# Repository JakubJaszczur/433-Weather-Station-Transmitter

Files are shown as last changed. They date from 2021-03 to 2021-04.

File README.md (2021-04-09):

<p align="center">
  <a href="" rel="noopener">
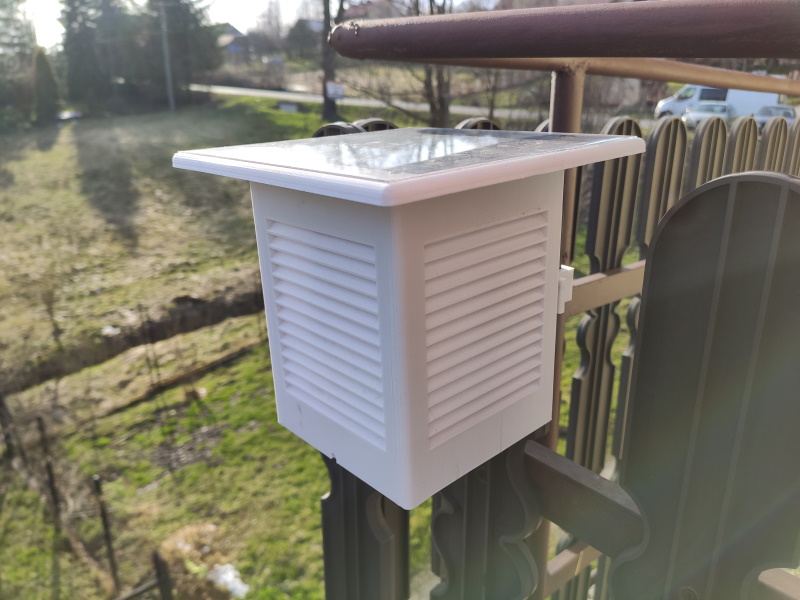
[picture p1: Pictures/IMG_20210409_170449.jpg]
Device
 </a>
</p>

<h1 align="center">Weather Station Transmitter</h1>

<div align="center">

[]()




</div>

---

<p align="center"> Weather Station based on HC12 transceiver
    <br> 
</p>

## Table of Contents

- [About](#about)
- [Features](#features)
- [Bill of Materials](#bill)
- [Libraries](#libraries)
- [Getting Started](#getting_started)
- [Description](#description)
- [Changelog](#changelog)
- [Task list](#task)
- [Pictures](#pictures)

## 1. About 

Weather Station powered by 18650 Li-ion battery, charged by solar panel. 433MHz HC-12 module is used to send data formatted in JSON. The project is a part of bigger IOT system, and is related to my other projects:

- [Epaper Weather Station Receiver](https://github.com/JakubJaszczur/Epaper-Weather-Station-Receiver "Epaper Weather Station Receiver")
- [Lora & HC12 to MQTT gateway](https://github.com/JakubJaszczur/LORA-433-Gateway "LORA 433 Gateway")

## 2. Features 

* Various sensors - temperature, humidity, pressure, light intensity, UV index, PM2.5, PM10
* Battery and solar panel voltage measurements
* Possibility to add more sensors (e.g. by I2C)
* Deep sleep to save power
* Debug mode

## 3. Bill of Materials 

Main components:

| Device  		 | Description 	 | Price		  | 
| --- | --- |---|
| Arduino Nano V3 | Main IC (clone) |	$2.50 |
| BME280 | Temperature, humidity, pressure sensor  |	$2.10 |
| MCP9808 | High accuracy temperature sensor | $0.75 |
| BH1750 | Light sensor | $1.00 |
| SI1145 | UV index sensor | $3.70 |
| PMS3003 | Dust sensor | $13.40 |
| HC12 | 433MHz transceiver | $1.95 |
| J5019 | Battery charger with DC-DC converter | $0.69 |
| 2000mAh Li-Ion  | 18650 Battery | $2.20 |
| 18650 holder | 18650 Battery holder | $0.35 |
| PC,B | Custom PCB | |
| Housing | Custom housing (3D printed) | |
<br>
## 4. Libraries 

- [ArduinoJson](https://github.com/bblanchon/ArduinoJson "ArduinoJson")
- [Adafruit MCP9808](https://github.com/adafruit/Adafruit_MCP9808_Library "Adafruit_MCP9808")
- [Adafruit BME280](https://github.com/adafruit/Adafruit_BME280_Library "Adafruit_BME280")
- [Adafruit Sensor](https://github.com/adafruit/Adafruit_Sensor "Adafruit_Sensor")
- [Adafruit SI1145](https://github.com/adafruit/Adafruit_SI1145_Library "Adafruit_SI1145")
- [BH1750 by Claws](https://github.com/claws/BH1750 "BH1750")
- [PMserial by Alvaro Valdebenito](https://github.com/avaldebe/PMserial "PMserial")

## 5. Getting Started 

To run Weather Station, user should change some settings:

Node ID - used to identify device by receiver 
```
#define NODE_ID           103   // Device ID, for internal purpose
```
Sleep time - how often device will wake up and send measurements 
```
#define SLEEP_TIME        37    // x * 8s = sleep time
```
Calibration factors - booth should be 1.0 at the beginning, later can be adjusted to fit measured voltages to real values
```
#define BAT_FACTOR        0.979981    // a = y/x, calibration factor
#define PAN_FACTOR        0.986017    // a = y/x, calibration factor
```
Altitude - set real value of your location, used for pressure readings
```
#define ALTITUDE        515.0 //define altitude of location
```

## 6. Description 

#### Measurements
- <b>Temperature:</b> measured by MCP9808 to ensure high accuracy (0,25&ordm;C)
- <b>Humidity, Pressure:</b> measured by BME280
- <b>Light:</b> measured by BH1750 (lux)
- <b>UV index:</b> measured by SI1145
- <b>PM2.5, PM10:</b> measured by PMS3003 
- <b>Voltages:</b> battery and solar panel voltages measured by analog inputs

#### Output Parameters

Measurements send by device using HC-12:

```json
{
  "id":103,
  "te":4,       // temperature
  "hu":72,      // humidity
  "pr":1024.8,  // pressure
  "p2":34,      // PM2.5
  "p1":45,      // PM10
  "ba":4.07,    // battery voltage
  "pa":4.794    // solar panel voltage
}
```

## 7. Changelog 

2021-04-09 <b>V1.0</b> Stable version  

## 8. Task list 

 Software:

- [ ] Service commands (receive data, e.g. calibration factors, sleep time and store in EEPROM)

Hardware:
- [ ] Add additional capacitor to Vcc for better stability
- [ ] Change MOSFET circuit - Q1 should be connected to GND, add gate-source resistor 
- [ ] For future - add anemometer, rainmeter, wind direction etc.

## 9. Pictures 

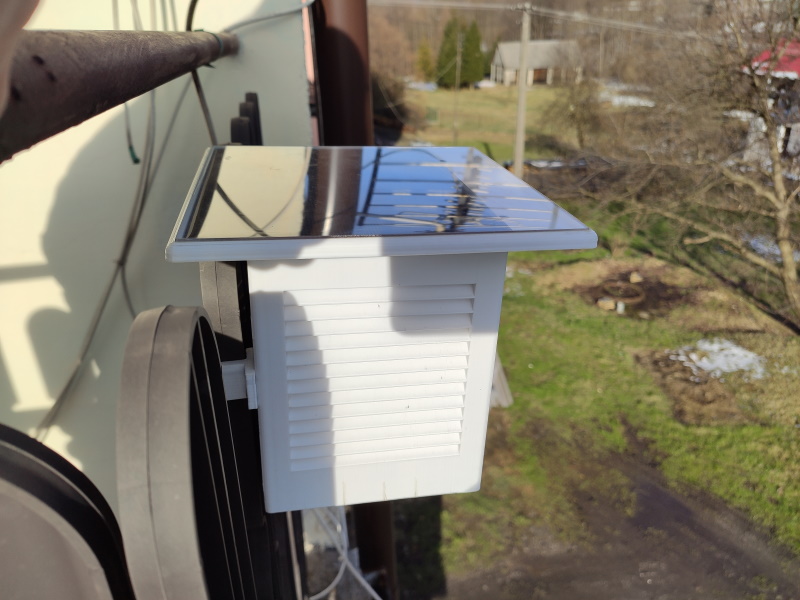
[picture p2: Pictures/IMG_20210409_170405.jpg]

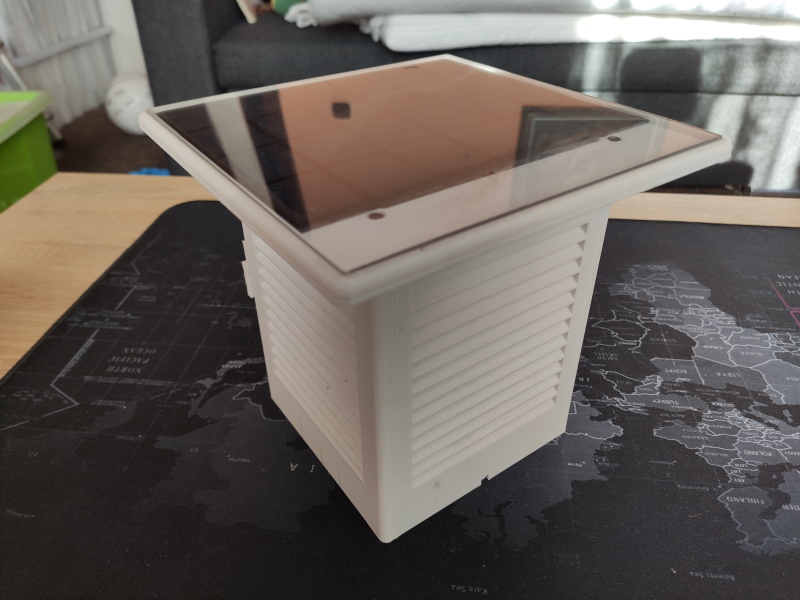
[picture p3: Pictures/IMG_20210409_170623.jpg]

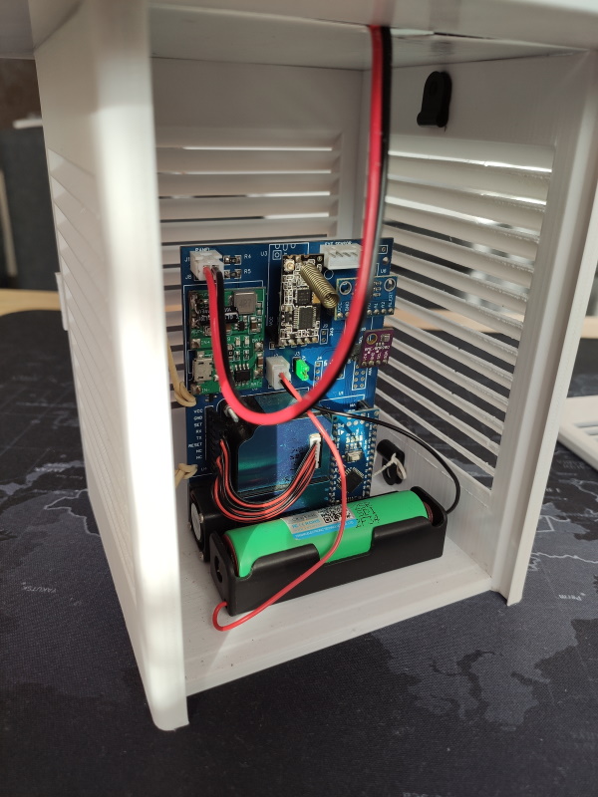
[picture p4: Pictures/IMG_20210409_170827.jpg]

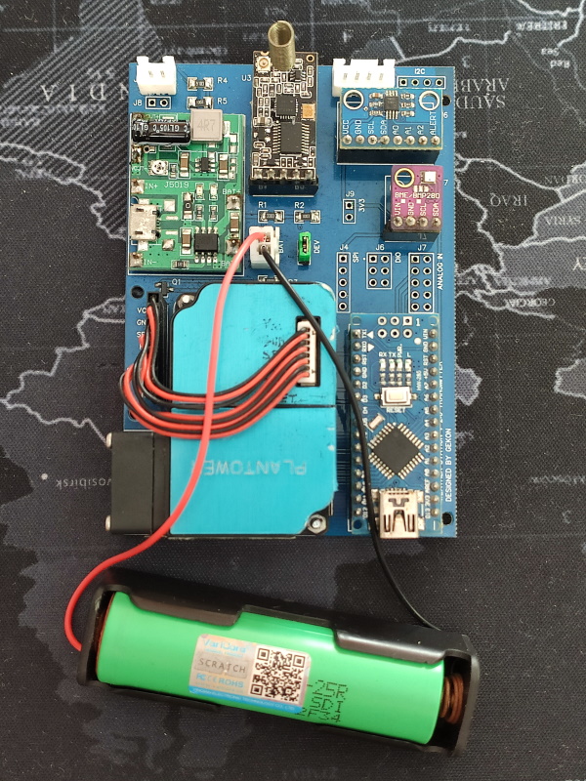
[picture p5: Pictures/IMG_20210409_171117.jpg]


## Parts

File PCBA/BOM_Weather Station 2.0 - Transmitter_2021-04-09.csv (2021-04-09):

ID | Name | Designator | Footprint | Quantity | Manufacturer Part | Manufacturer | Supplier | Supplier Part | Price | LCSC Assembly
1 | Header-Male-2.54_1x2 | J1,J2,J3,J8,J9 | HDR-2X1/2.54 | 5 | 826629-2 | TE Connectivity | LCSC | C86471 | 0.2091
2 | Header-Male-2.54_1x5 | J4 | HDR1X5 | 1 | 210S-1*5P L=11.6MMGold-plated black | Ckmtw | LCSC | C124379 | 0.0327
3 | Header-Male-2.54_2x3 | J6 | HDR-TH_6PIN-V-ROW2-COL3-MALE-PITCH2.54 | 1 | Header-Male-2.54_2x3 | BOOMELE | LCSC | C65114 | 0.0237
4 | 210S-2*5P L=11.6MMGold-plated black | J7 | CON 5X2 PIN | 1 | 210S-2*5P L=11.6MMGold-plated black | Ckmtw | LCSC | C124387 | 0.0472
5 | Header-Male-2.54_1x4 | J5,J10,J11 | HDR1X4 | 3 | 210S-1*4P L=11.6MMGold-plated black | Ckmtw | LCSC | C124378 | 0.0261
6 | 2N7002K | Q1 | SOT-23-3_L2.9-W1.3-P1.90-LS2.4-BR | 1 | 2N7002K | Hottech | LCSC | C181083 | 0.0136 | Yes
7 | 330k | R1 | 1206 | 1
8 | 100k | R2,R5 | 1206 | 2
9 | 100R | R3 | 1206 | 1
10 | 680k | R4 | 1206 | 1
11 | ARDUINO NANO V3 | U1 | ARDUINO NANO V3 NO ICSP | 1
12 | J5019 | U2 | J5019 | 1
13 | HC-12 | U3 | HC-12 | 1
14 | PMS3003 | U4 | PMS3003 | 1
15 | BH1750 | U5 | BH1750 | 1
16 | MCP9808 | U6 | MCP9808 | 1
17 | BME280 | U7 | BME280 | 1
18 | SI1145 | U8 | SI1145 | 1

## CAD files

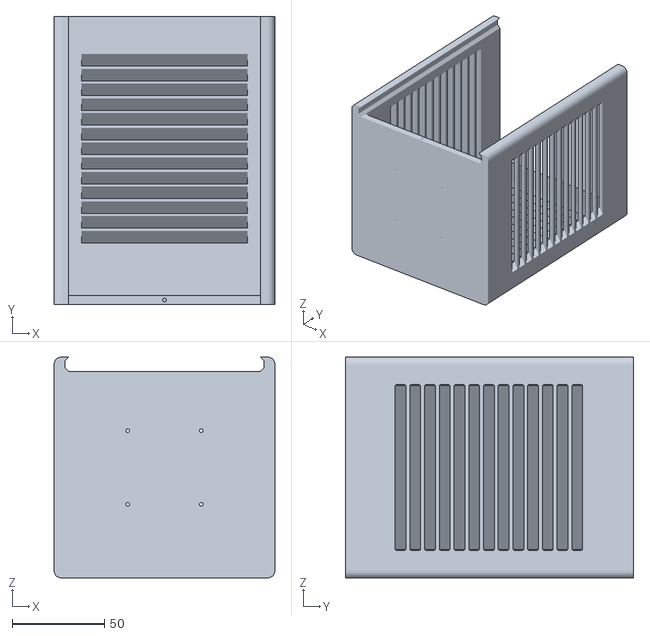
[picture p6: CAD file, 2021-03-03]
Mechanical/MainBody.stl
120.0 x 156.5 x 120.0

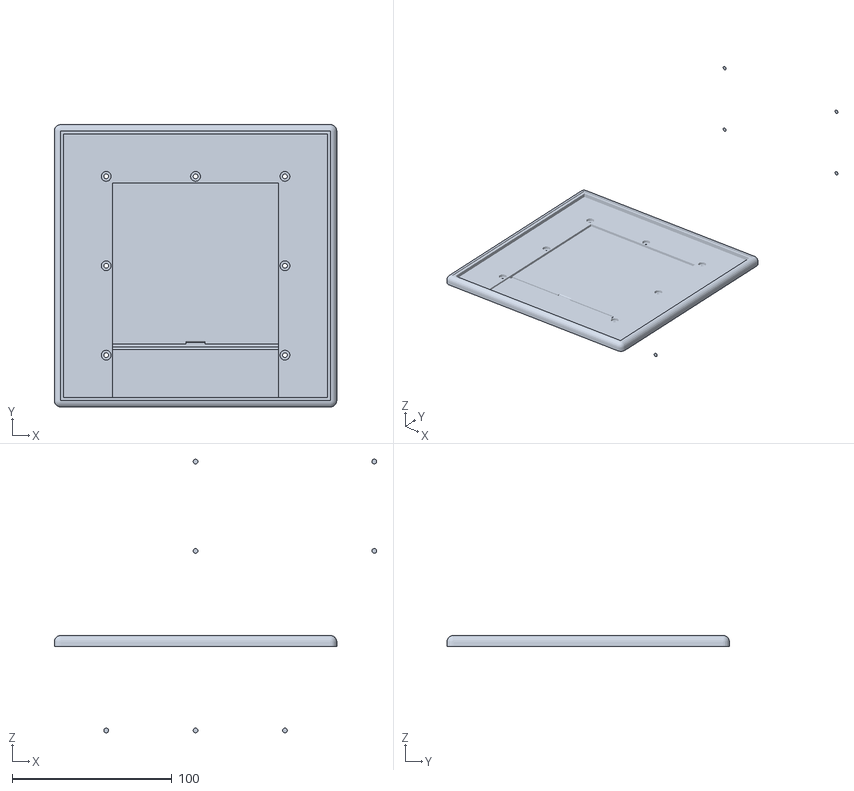
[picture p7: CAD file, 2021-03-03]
Mechanical/Cover.stl
202.0 x 245.0 x 171.5

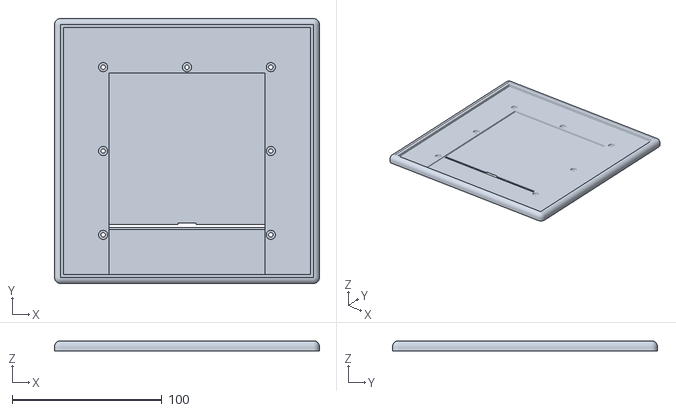
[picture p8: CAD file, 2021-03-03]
Mechanical/Cover.rsdoc.stl
177.0 x 177.0 x 7.00

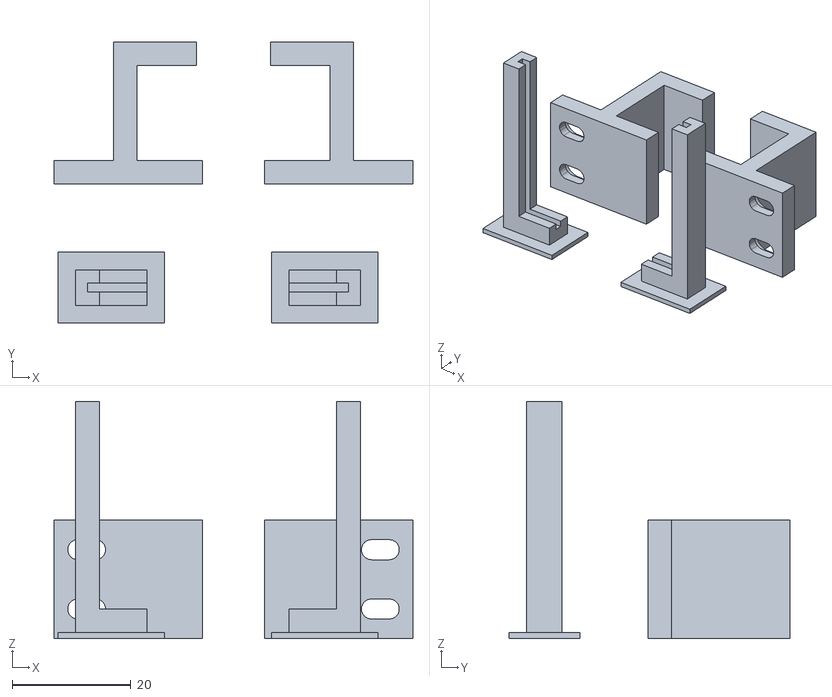
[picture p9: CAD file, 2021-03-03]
Mechanical/Holders.stl
60.5 x 47.4 x 40.0

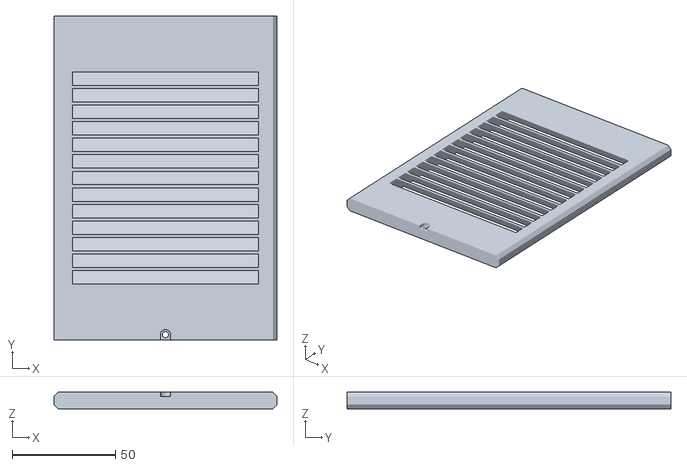
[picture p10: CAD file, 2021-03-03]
Mechanical/Front.stl
107.8 x 156.5 x 8.00

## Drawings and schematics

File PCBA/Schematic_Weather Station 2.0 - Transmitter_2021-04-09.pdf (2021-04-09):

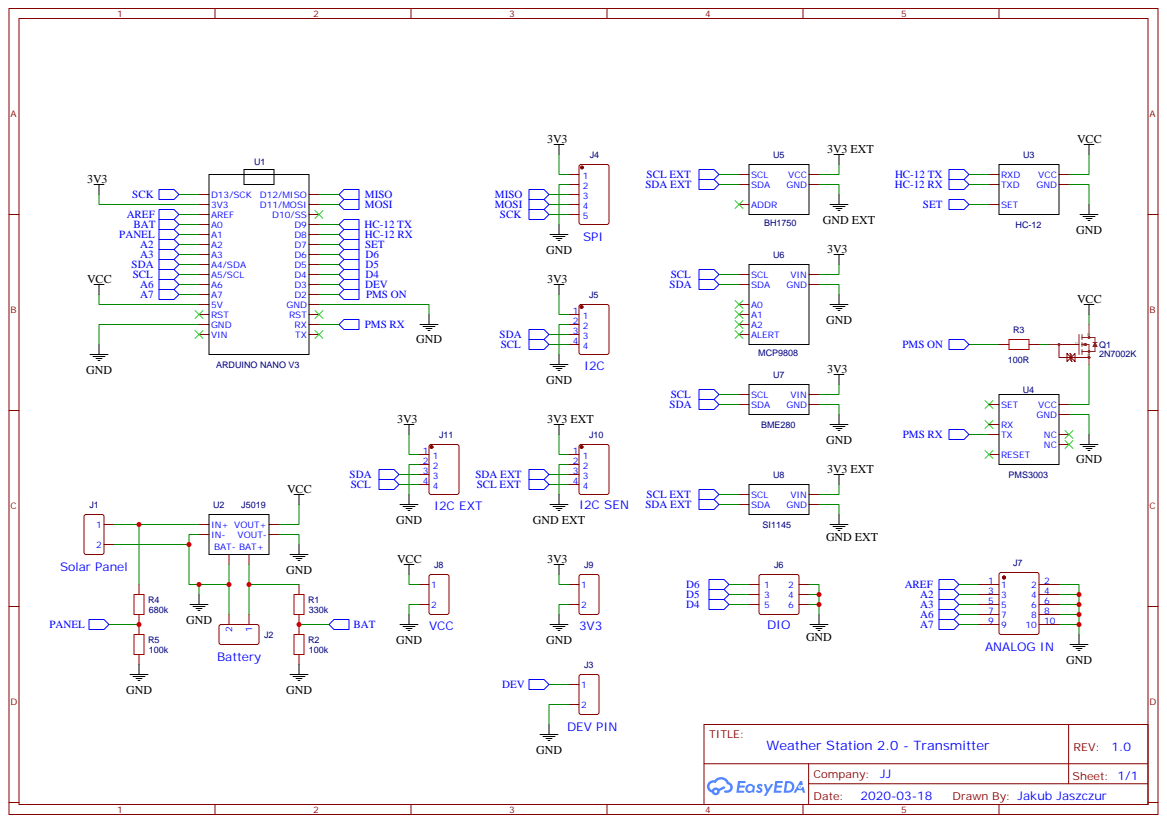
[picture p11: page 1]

Drawn By: Jakub Jaszczur

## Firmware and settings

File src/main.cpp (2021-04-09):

#include <Arduino.h>
#include <ArduinoJson.h>
#include <SoftwareSerial.h>
#include <math.h>
#include "LowPower.h"

// Sensors
#include <Wire.h>
#include "Adafruit_MCP9808.h"
#include <Adafruit_Sensor.h>
#include <Adafruit_BME280.h>
#include <BH1750.h>
#include "Adafruit_SI1145.h"
#include <PMserial.h>

#define NODE_ID           103   // Device ID, for internal purpose
#define CONFIG_PIN        3     // D3, set maintenance mode
#define SLEEP_TIME        37    // x * 8s = sleep time
#define PMS_SET           2     // D2
#define RX_PIN            8     // D8
#define TX_PIN            9     // D9
#define SET_PIN           7     // D7
#define MEASURE_NUMBER    2     // Number of Smog measurements to average
#define BATTERY_PIN       A0    // Battery voltage measurement
#define PANEL_PIN         A1    // Solar Panel voltage measurement
#define BATTERY_DIVIDER   0.232558      // R2 = 100k, R1 = 330k   R2/(R1 + R2), use real (measured vales)
#define PANEL_DIVIDER     0.163934      // R5 = 100k, R4 = 510k   R5/(R4 + R5), use real (measured vales)
#define REF_VOLTAGE       1.1
#define BAT_FACTOR        0.979981    // a = y/x, calibration factor, y = real value, e.g 4.2V, x = value calculated, e.g. 4.15V
#define PAN_FACTOR        0.986017    // a = y/x, calibration factor, y = real value, e.g 4.2V, x = value calculated, e.g. 4.15V

// Sensors config data
#define ALTITUDE        515.0 //define altitude of location
#define BME280_ADDR     0x76  //BME280 I2C Address
#define MCP9808_ADDR    0x18  //MCP9808 I2C Address

// I2C settings
#define BME_SCK         28  //SCL
#define BME_CS          27  //SDA

SerialPM pms(PMSx003, Serial);          // PMSx003, UART
SoftwareSerial HC12(RX_PIN, TX_PIN);    // HC-12 TX Pin, HC-12 RX Pin

Adafruit_MCP9808 tempsensor = Adafruit_MCP9808();   // temp
Adafruit_BME280 bme;                                // temp, hum, press
BH1750 lightMeter;                                  // lux
Adafruit_SI1145 uv = Adafruit_SI1145();             // uv

// Globals

int pm10;
int pm25;

// Status variables

boolean SI1145initStatus = false;
boolean BH1750initStatus = false;
boolean MCP9808initStatus = false;
boolean BME280initStatus = false;
boolean PMS3003initStatus = false;

// SI1145 functions

boolean InitialiseSI1145()
{
  if(!uv.begin()) 
  {
    Serial.println("SI1145 Error");
    return false;
  }
  else
  {
    Serial.println("SI1145 Initialised");
    return true;
  }
}

float GetUVindex()
{
  float index = uv.readUV();
  index /= 100;

  return index;
}

// BH1750 functions

boolean InitialiseBH1750()
{
  if(!lightMeter.begin(BH1750::ONE_TIME_LOW_RES_MODE)) 
  {
    Serial.println("BH1750 Error");
    return false;
  }
  else
  {
    Serial.println("BH1750 Initialised");
    return true;
  }
}

float GetLightBH1750()
{
  float light = lightMeter.readLightLevel();

  return light;
}

// MCP9808 functions

boolean InitialiseMPC9808(byte mode)
{
  if(!tempsensor.begin(MCP9808_ADDR)) 
  {
    Serial.println("MCP9808 Error");
    return false;
  }
  else
  {
    Serial.println("MCP9808 Initialised");
    tempsensor.setResolution(mode); // sets the resolution mode of reading, the modes are defined in the table bellow:
  // Mode Resolution SampleTime
  //  0    0.5°C       30 ms
  //  1    0.25°C      65 ms
  //  2    0.125°C     130 ms
  //  3    0.0625°C    250 ms
    return true;
  }
}

float GetTemperatureMCP9808()
{
  tempsensor.wake();   // wake up, ready to read!
  float temperature = tempsensor.readTempC();
  tempsensor.shutdown_wake(1); // shutdown MSP9808 - power consumption ~0.1 mikro Ampere, stops temperature sampling

  return temperature;
}

// BME280 functions

boolean InitialiseBME280()
{
  if (!bme.begin(BME280_ADDR, &Wire))
  //if (!bme.begin())  
  {
    Serial.println("BME280 Error");
    return false;
  }
  else
  {
    Serial.println("BME280 Initialised");
    return true;
  }
  
}

// Not used
/* float GetTemperatureBME280()
{
  float temperature = bme.readTemperature();
  
  return temperature;
} */

float GetHumidityBME280()
{
  float humidity = bme.readHumidity();
  
  return humidity;
}

float GetPressureBME280()
{
  float pressure = bme.readPressure();
  pressure = bme.seaLevelForAltitude(ALTITUDE, pressure);
  pressure = pressure / 100.0F;
  
  return pressure;
}

// PMS3003 functions

void GetPollution()
{
  int tempPM10 = 0;
  int tempPM25 = 0;

  digitalWrite(PMS_SET, HIGH);
  delay(200);
  
  for(int i = 0; i < MEASURE_NUMBER; i ++)
  {
    int timeout = 0;

    do
    {
      pms.read();
      timeout ++;
    } while (!pms && timeout < 20);

    tempPM25 += pms.pm25;
    tempPM10 += pms.pm10;
  }
  
  if(pms)
  {  // successfull read
    pm25 = tempPM25 / MEASURE_NUMBER;
    pm10 = tempPM10 / MEASURE_NUMBER;

    PMS3003initStatus = true;
  } 
  else 
  { // something went wrong
    pm25 = -100;
    pm10 = -100;

    switch (pms.status) 
    {
        case pms.OK: // should never come here
          break;     // included to compile without warnings
        case pms.ERROR_TIMEOUT:
          Serial.println(F(PMS_ERROR_TIMEOUT));
          break;
        case pms.ERROR_MSG_UNKNOWN:
          Serial.println(F(PMS_ERROR_MSG_UNKNOWN));
          break;
        case pms.ERROR_MSG_HEADER:
          Serial.println(F(PMS_ERROR_MSG_HEADER));
          break;
        case pms.ERROR_MSG_BODY:
          Serial.println(F(PMS_ERROR_MSG_BODY));
          break;
        case pms.ERROR_MSG_START:
          Serial.println(F(PMS_ERROR_MSG_START));
          break;
        case pms.ERROR_MSG_LENGTH:
          Serial.println(F(PMS_ERROR_MSG_LENGTH));
          break;
        case pms.ERROR_MSG_CKSUM:
          Serial.println(F(PMS_ERROR_MSG_CKSUM));
          break;
        case pms.ERROR_PMS_TYPE:
          Serial.println(F(PMS_ERROR_PMS_TYPE));
          break;
    }
  
    PMS3003initStatus = false;    
  }

  digitalWrite(PMS_SET, LOW);
}

// Read battery voltage

float GetVoltage(int pinNumber, float divider, int iterations, float calibrationFactor)
{
  float rawVoltage = 0;

  analogRead(pinNumber); //for stable measurements, drop first one

  for(int i = 0; i < iterations; i ++)
  {
    rawVoltage = rawVoltage + analogRead(pinNumber);
  }

  rawVoltage = rawVoltage / iterations;

  float measurement = (((rawVoltage / 1023) * REF_VOLTAGE) / divider) * calibrationFactor;

  return measurement;
}

// Sending message

void SendCommand(String command)
{
  digitalWrite(SET_PIN, LOW);
  delay(100);
  HC12.print(command);
  delay(100);
  while (HC12.available()) 
  {           // If HC-12 has data (the AT Command response)
    Serial.write(HC12.read());         // Send the data to Serial monitor
  }
  digitalWrite(SET_PIN, HIGH);
  delay(100);
}

// Make JSON message

String ComposeJSONmessage(int id, float temp, float hum, float press, float lux, float uv, int pm_25, int pm_10, float bat, float panel)
{
  String message;

  const size_t capacity = JSON_OBJECT_SIZE(10) + 90;
  DynamicJsonDocument doc(capacity);

  doc["id"] = id;

  if(MCP9808initStatus)
    doc["te"] = roundf(temp * 100) / 100.0;
  if(BME280initStatus)
  {
    doc["hu"] = roundf(hum * 10) / 10.0;
    doc["pr"] = roundf(press * 10) / 10.0;
  }
  if(BH1750initStatus)
    doc["li"] = roundf(lux);
  if(SI1145initStatus)
    doc["uv"] = roundf(uv * 100) / 100.0;
  if(PMS3003initStatus)
  {
    doc["p2"] = pm_25;
    doc["p1"] = pm_10;
  }
  doc["ba"] = roundf(bat * 1000) / 1000.00;
  doc["pa"] = roundf(panel * 1000) / 1000.00;

  serializeJson(doc,message);

  return message;
}

// Check maintenance mode

unsigned int CheckMode(unsigned int pin)
{
  unsigned int time;

  if(digitalRead(pin) == HIGH)
    time = 1;
  else
    time = SLEEP_TIME;
  
  return time;
}

void setup() 
{
  Serial.begin(9600);
  HC12.begin(9600);

  Wire.begin();

  // Initialise sensors and report status
  MCP9808initStatus = InitialiseMPC9808(2);
  BME280initStatus =  InitialiseBME280();
  BH1750initStatus = InitialiseBH1750();
  SI1145initStatus = InitialiseSI1145();

  // Pin mode setup
  pinMode(CONFIG_PIN, INPUT_PULLUP);
  pinMode(BATTERY_PIN, INPUT);
  pinMode(PANEL_PIN, INPUT);
  pinMode(PMS_SET, OUTPUT);
  pinMode(SET_PIN, OUTPUT);

  analogReference(INTERNAL);

  // Initialise PMS
  digitalWrite(PMS_SET, HIGH);
  delay(100);
  pms.init();
  digitalWrite(PMS_SET, LOW);
}

void loop() 
{ 
  float tempOut = 0;
  float humOut = 0;
  float pressOut = 0;
  float lightOut = 0;
  float UVindex = 0;

  // Get measurements only if device is initialised
  if(MCP9808initStatus)
    tempOut = GetTemperatureMCP9808();
  if(BME280initStatus)
  {
    humOut = GetHumidityBME280();
    pressOut = GetPressureBME280();
  }
  if(BH1750initStatus)
    lightOut = GetLightBH1750();
  if(SI1145initStatus)
    UVindex = GetUVindex();
  if(tempOut > - 10.0)  // Measure pollution only if temperature is above -10 C
    GetPollution();
  else
    PMS3003initStatus = false;

  float batteryVoltage = GetVoltage(BATTERY_PIN, BATTERY_DIVIDER, 5, BAT_FACTOR);
  //delay(50);
  float panelVoltage = GetVoltage(PANEL_PIN, PANEL_DIVIDER, 5, PAN_FACTOR);
  
  String messToSend = ComposeJSONmessage(NODE_ID, tempOut, humOut, pressOut, lightOut, UVindex, pm25, pm10, batteryVoltage, panelVoltage);
  SendCommand("AT");
  Serial.println(messToSend);
  HC12.println(messToSend);      // Send that data to HC-12
  delay(50);
  SendCommand("AT+SLEEP");
  
  int counter = CheckMode(CONFIG_PIN);

  for(int i = 0; i < counter; i ++)   // sleep time depends on config pin
    LowPower.powerDown(SLEEP_8S, ADC_ON, BOD_OFF);
  delay(50);
}

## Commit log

2021-02-06 Add mechanical project of housing
2021-02-07 Change dimensions Add STL files
    [Cover.stl, Front.stl, Holders.stl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]
2021-02-07 Modify missed files
    [Holders.stl]
2021-02-18 Change voltage measurement method
    Add voltage averaging using defined number of iterations. Add calibration factor
2021-02-18 Change battery and panel voltage precision
    Change precision of values in JSON messages
2021-03-03 Change some dimensions
    Adjust some dimensions to fit real tolerances and add some space for
    sensors (cover)
    [Cover.rsdoc.stl, Front.stl, Holders.stl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]
2021-03-03 Change cover layout
    Improvements
    [Cover.stl]
2021-03-03 Change calibration values
2021-04-09 Add readme, PCBA files
    [BOM_Weather Station 2.0 - Transmitter_2021-04-09.csv]

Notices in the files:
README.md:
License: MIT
